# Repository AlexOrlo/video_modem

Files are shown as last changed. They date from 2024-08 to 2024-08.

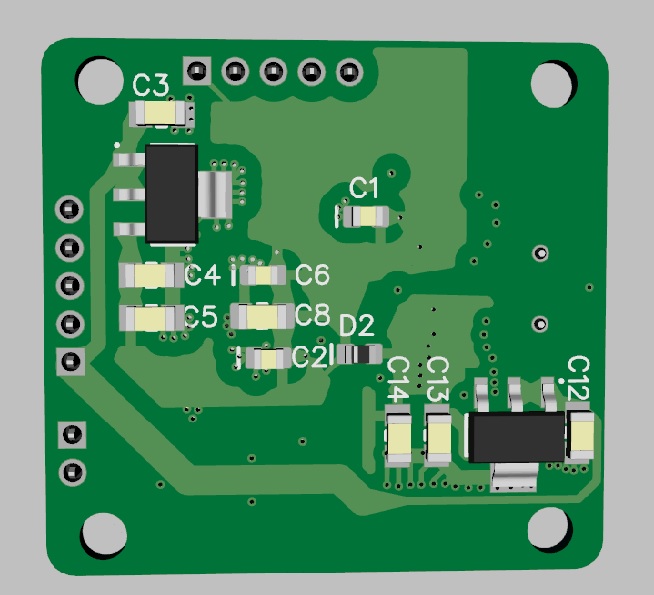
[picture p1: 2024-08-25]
tx/down.jpg

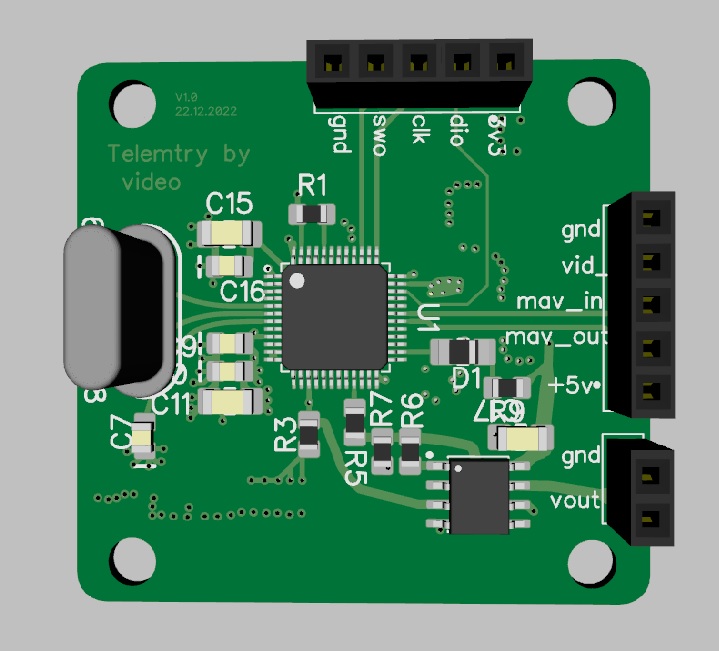
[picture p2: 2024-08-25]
tx/up.jpg

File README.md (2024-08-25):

Telemetry Transmission via Analog Video

This is a small project that allows for receiving digital data (telemetry) through analog video. 
Although most control systems today have a feedback channel, it is not always possible to use it. 
For instance, it might be prohibited in competitions or if the power and range are limited.

Personally, I use it as a receiving modem on my ground-based rotating antenna stations with analog video.

The device allows for data transmission at speeds of up to 800 bytes per second in PAL system and up to 720 bytes per second in NTSC system. 
An 8KB buffer helps handle short-term bursts in speed.

To optimize the use of the narrow channel, message type filtering for MAVLink and Crossfire protocols is supported. 
For example, I only use the MAVLink HIGH_LATENCY2 message, which contains all the necessary information and occupies 42 bytes. 
This allows setting the maximum update frequency of such a message to 800/42 = 19 times per second.

MAVLink Message List:

    SYS_STATUS 		43 bytes
    SCALED_IMU  	24 bytes
    ATTITUDE 		28 bytes
    GLOBAL_POSITION_INT 28 bytes
    VFR_HUD 		20 bytes
    ALTITUDE  		32 bytes
    HIGH_LATENCY2  	42 bytes

Crossfire Message List:

    CRSF_FRAMETYPE_VARIO 	6 bytes
    CRSF_FRAMETYPE_BARO_ALT 	6 bytes
    CRSF_FRAMETYPE_GPS 		19 bytes
    CRSF_FRAMETYPE_LINK 	14 bytes
    CRSF_FRAMETYPE_BATTERY 	11 bytes
    CRSF_FRAMETYPE_ATTITUDE 	10 bytes
    CRSF_FRAMETYPE_FLIGHT_MODE 	<=20 bytes

It is also possible to transmit any raw data without any filtering.
For configuring the filter, selecting the protocol, and setting the UART port speed, commands are used via the serial terminal.
Both the transmitting and receiving devices are built on an STM32F303CBT6 microcontroller. 
The GitHub repository contains ready-made projects for Keil MDK as well as schematics and PCBs in DipTrace.
Ready binaries and Gerber files for the PCBs are also available.

To assemble the device, you need the following components: two STM32F303CBTx, one dual operational amplifier MAX4017ESA+, 
four MC33375ST-3.3T3 regulators, two 8MHz crystal oscillators, and a selection of SMD capacitors and resistors in 0805 package. 
The transmitting device has a form factor of 38x38 mm and a standard mounting hole distance of 30.5 mm.

If anyone is interested, let me know, and I can provide more detailed information on its configuration. 
Additionally, when using a full MAVLink setup (PX4/ArduPilot), I can add the capability to configure the message transmission frequency 
(the flight controller must support the MAV_CMD_SET_MESSAGE_INTERVAL command).

Interestingly, this device does not introduce any distortions in the video, works stably in interference conditions, 
and only fails in cases of total video degradation (when nothing is visible on the screen).

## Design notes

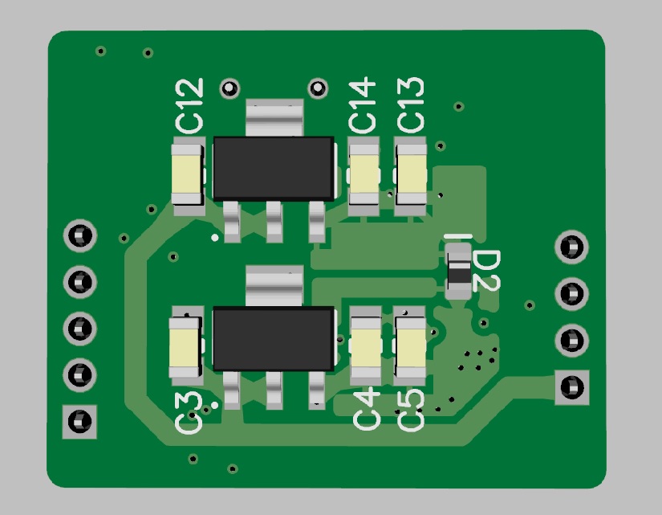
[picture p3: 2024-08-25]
rx/down.jpg

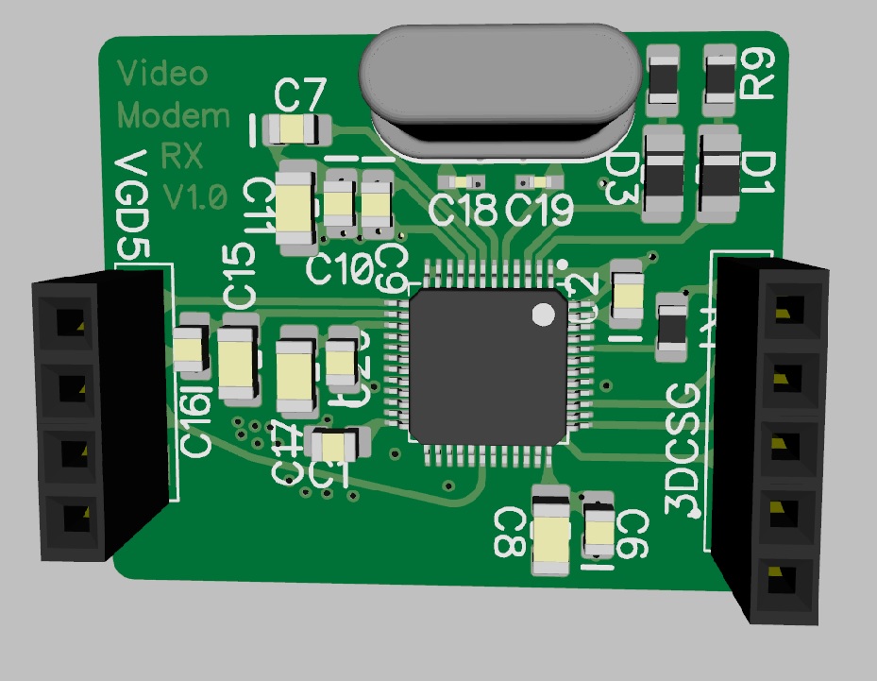
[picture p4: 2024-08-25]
rx/up.jpg

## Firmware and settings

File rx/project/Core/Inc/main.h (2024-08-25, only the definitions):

#define LED_OK_Pin GPIO_PIN_13
#define LED_OK_GPIO_Port GPIOC
#define LED_ERROR_Pin GPIO_PIN_14
#define LED_ERROR_GPIO_Port GPIOC
#define VIDEO_BUF_OUT_AMP1_VOUT_Pin GPIO_PIN_2
#define VIDEO_BUF_OUT_AMP1_VOUT_GPIO_Port GPIOA
#define VIDEO_IN_AMP1_VNP_Pin GPIO_PIN_3
#define VIDEO_IN_AMP1_VNP_GPIO_Port GPIOA
#define VREF_250mv_DAC_1_Pin GPIO_PIN_4
#define VREF_250mv_DAC_1_GPIO_Port GPIOA
#define VREF_1000mV_Pin GPIO_PIN_5
#define VREF_1000mV_GPIO_Port GPIOA
#define UART_3_RX_Pin GPIO_PIN_10
#define UART_3_RX_GPIO_Port GPIOB
#define DATA_OUT_Pin GPIO_PIN_9
#define DATA_OUT_GPIO_Port GPIOA
#define TO_UART3_Pin GPIO_PIN_12
#define TO_UART3_GPIO_Port GPIOA
#define LED_OK_TURN_ON       LED_OK_GPIO_Port->BRR     = (uint32_t)LED_OK_Pin
#define LED_OK_TURN_OFF      LED_OK_GPIO_Port->BSRR    = (uint32_t)LED_OK_Pin
#define LED_OK_TOGGLE        LED_OK_GPIO_Port->BSRR = ((LED_OK_GPIO_Port->ODR & LED_OK_Pin) << 16U) | (~LED_OK_GPIO_Port->ODR & LED_OK_Pin)
#define LED_ERROR_TURN_ON    LED_ERROR_GPIO_Port->BRR  = (uint32_t)LED_ERROR_Pin
#define LED_ERROR_TURN_OFF   LED_ERROR_GPIO_Port->BSRR = (uint32_t)LED_ERROR_Pin
#define LED_ERROR_TOGGLE     LED_ERROR_GPIO_Port->BSRR = ((LED_ERROR_GPIO_Port->ODR & LED_ERROR_Pin) << 16U) | (~LED_ERROR_GPIO_Port->ODR & LED_ERROR_Pin)

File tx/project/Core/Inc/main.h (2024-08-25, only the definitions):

#define CLI_NAME video_tx_cli
#define LED_Pin GPIO_PIN_13
#define LED_GPIO_Port GPIOB
#define VIDEO_BUF_OUT_AMP1_VOUT_Pin GPIO_PIN_2
#define VIDEO_BUF_OUT_AMP1_VOUT_GPIO_Port GPIOA
#define NEG_FEED_AMP1_VNM_Pin GPIO_PIN_3
#define NEG_FEED_AMP1_VNM_GPIO_Port GPIOA
#define VREF_55mv_DAC_1_Pin GPIO_PIN_4
#define VREF_55mv_DAC_1_GPIO_Port GPIOA
#define VIDEO_IN_AMP1_VNP_Pin GPIO_PIN_5
#define VIDEO_IN_AMP1_VNP_GPIO_Port GPIOA
#define SUM_IN_AMP3_VNP_Pin GPIO_PIN_0
#define SUM_IN_AMP3_VNP_GPIO_Port GPIOB
#define VIDEO_OUT_AMP3_VOUT_Pin GPIO_PIN_1
#define VIDEO_OUT_AMP3_VOUT_GPIO_Port GPIOB
#define NEG_FEED_AMP3_VNM_Pin GPIO_PIN_2
#define NEG_FEED_AMP3_VNM_GPIO_Port GPIOB
#define DATA_FOR_VIDEO_USART3_TX_Pin GPIO_PIN_10
#define DATA_FOR_VIDEO_USART3_TX_GPIO_Port GPIOB
#define UART1_MAV_TX_Pin GPIO_PIN_9
#define UART1_MAV_TX_GPIO_Port GPIOA
#define UART1_MAV_RX_Pin GPIO_PIN_10
#define UART1_MAV_RX_GPIO_Port GPIOA
#define DMA_BUF_SIZE_U1 1024
#define DMA_TIMEOUT_MS_U1      2
#define LED_Off   LED_GPIO_Port->BRR = (uint32_t)LED_Pin
#define LED_On  LED_GPIO_Port->BSRR = (uint32_t)LED_Pin
#define LED_Toggle LED_GPIO_Port->BSRR = ((LED_GPIO_Port->ODR & LED_Pin) << 16U) | (~(LED_GPIO_Port->ODR) & LED_Pin)

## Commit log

2024-08-25 Added pcb pictures
2024-08-25 added uart cal for rx

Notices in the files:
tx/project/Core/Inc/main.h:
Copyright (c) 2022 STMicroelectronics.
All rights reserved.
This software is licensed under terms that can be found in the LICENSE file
